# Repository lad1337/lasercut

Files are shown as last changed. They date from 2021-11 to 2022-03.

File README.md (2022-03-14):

# Lasercut

PCB and case for an "iso" 72 key mechanical keyboard

## Layout

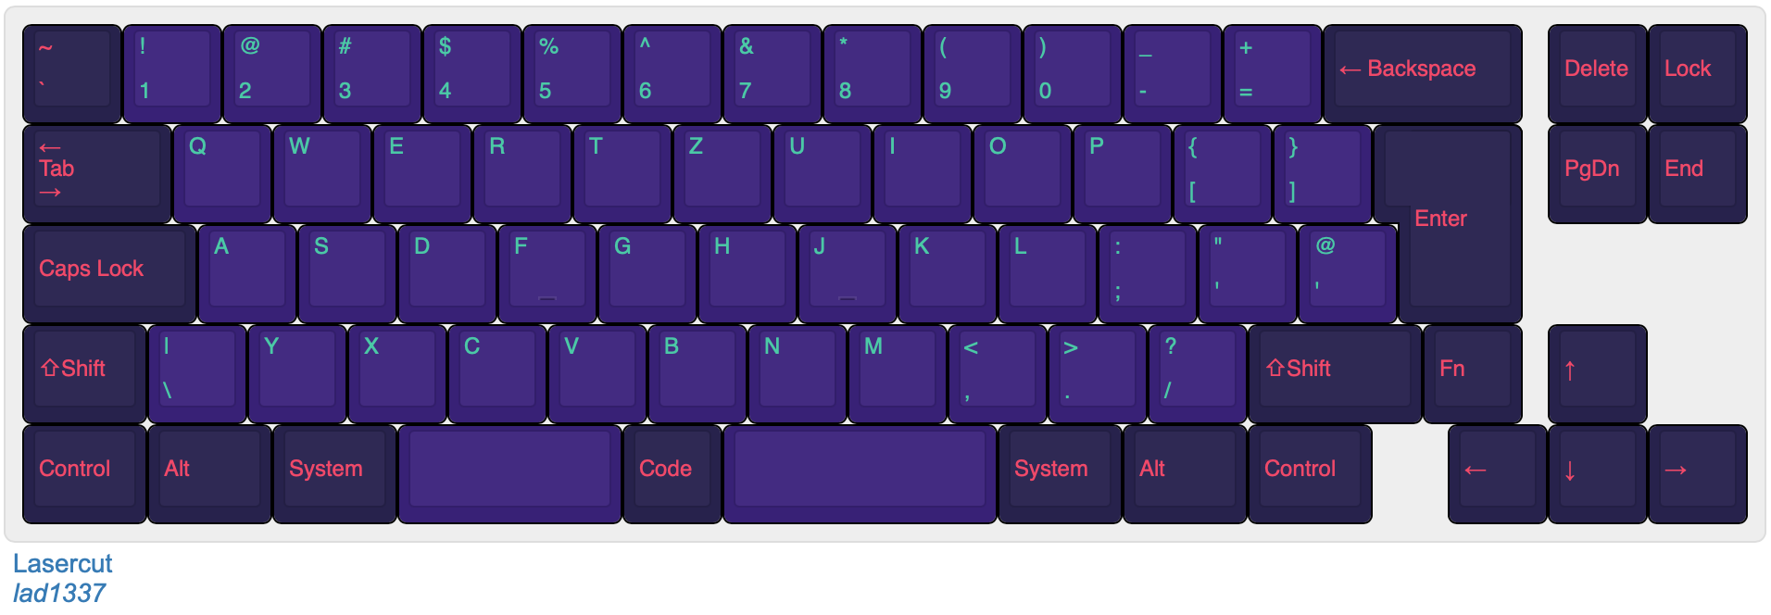
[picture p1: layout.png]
rendered image from keybaord layout editor


http://www.keyboard-layout-editor.com/#/gists/ba62eb48125304c6f380ac636846d038

## Case

The case is a sandwich style.
The plates can be rendered at http://builder.swillkb.com/
which is based on https://github.com/swill/kad.

in the case folder you will find a small go app(source) that can achive the same.

prerequisite:
    
    brew install inkscape pstoedit

render:

    cd case
    go run main.go

This will render svg, eps and dxf files.
These can be used with any CAD software.

You will need the following plates:

- 1x switch plate in 1.5mm
- 1x closed with magnets inserts in 3mm (not automatically rendered!!)
- 2x closed in 3mm
- 1x switch in 1.5mm
- 1x open in 3mm
- 1x bottom in 1-3mm

Example render in fusion with stainless steel and brass

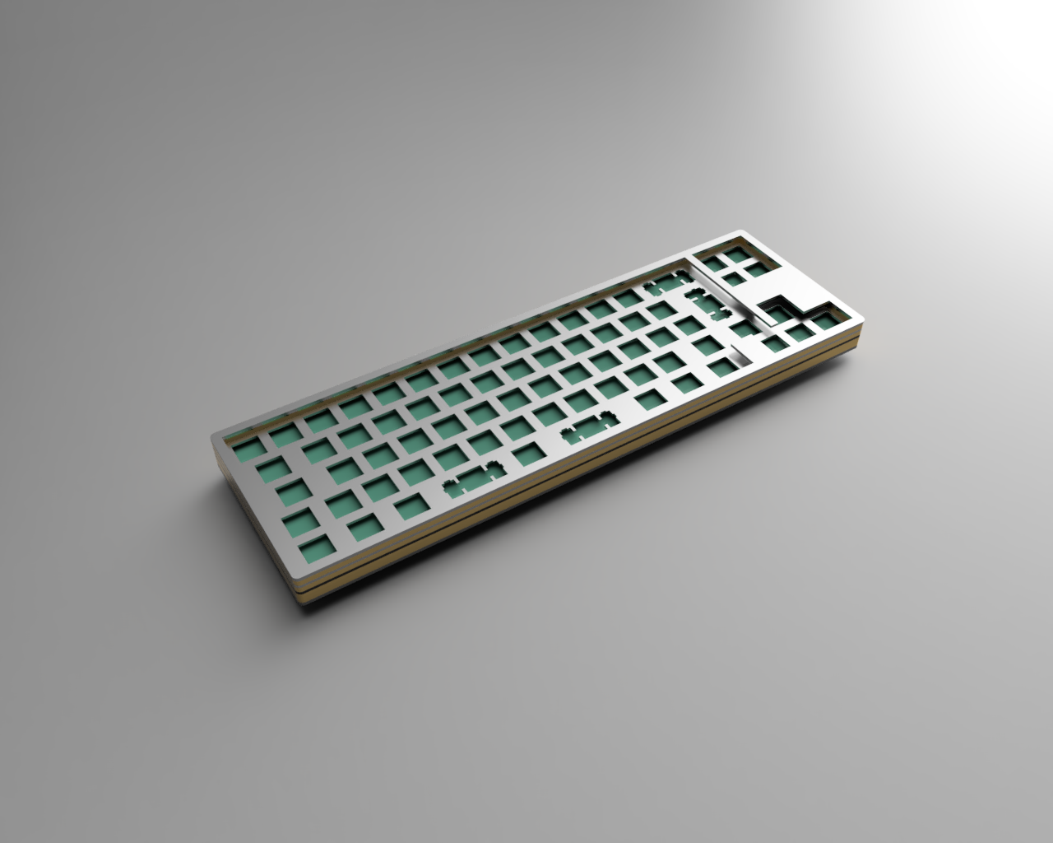
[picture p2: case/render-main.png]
3D render top side view

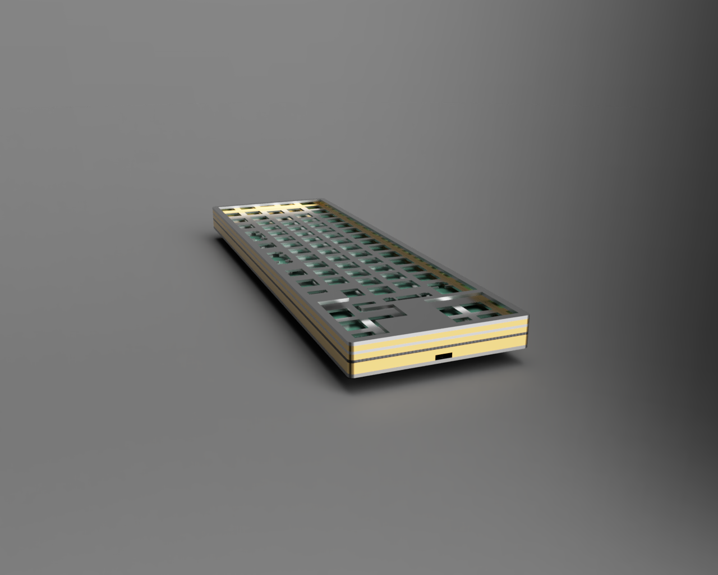
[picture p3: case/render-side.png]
3D render side view


## PCB

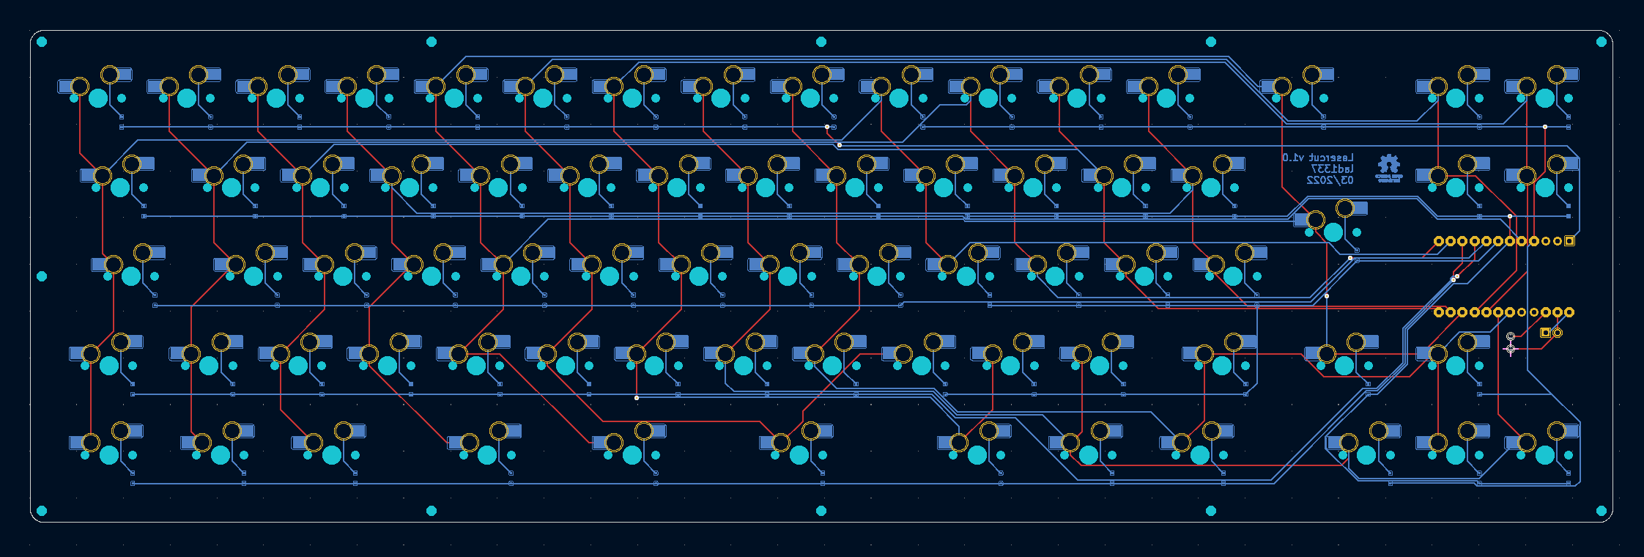
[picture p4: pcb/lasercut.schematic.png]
full board schematics

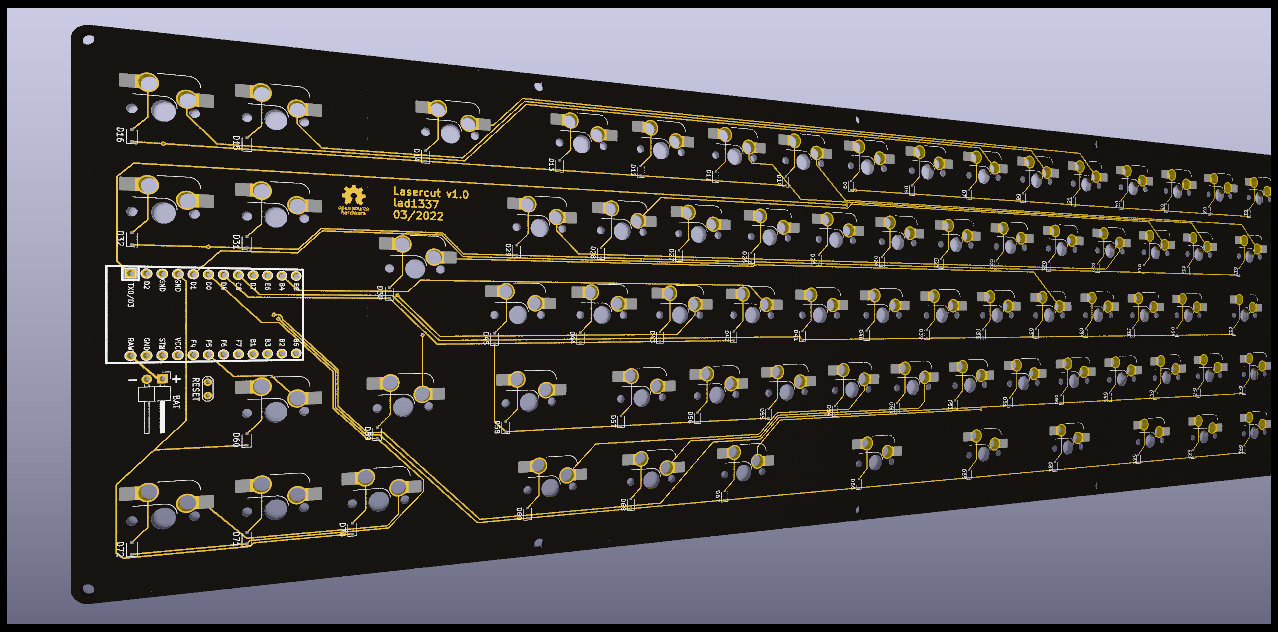
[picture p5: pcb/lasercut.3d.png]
3D render of PCB backside


### Board edge

add the generated `./case/Lasercut_bottom.dxf` to the board and position:

    x: 23.0
    y: 19.94769

TODO: mounting holes

### Netlist

prerequisite: 

- `kle2netlist` installed, see https://github.com/lad1337/kle2netlist
    this will create a netlist from the kle json
- `kicad-kbplacer` kicad plugin installed, see https://github.com/lad1337/kicad-kbplacer
    this is a plugin that will place the swiches to the right place as well as create some tracks
- `node` and `npm install @ijprest/kle-serial --save` 
    this is needed for converting the kle json to its internal format

Steps:

- run:
    `make netlist`
- import the netlist into pcbnew
- run the kicad-kbplacer plugin
- rearrage the controller

    ```
    x: 335.4
    y: 72.6
    roation: 180
    ```
- finish all the other tracks

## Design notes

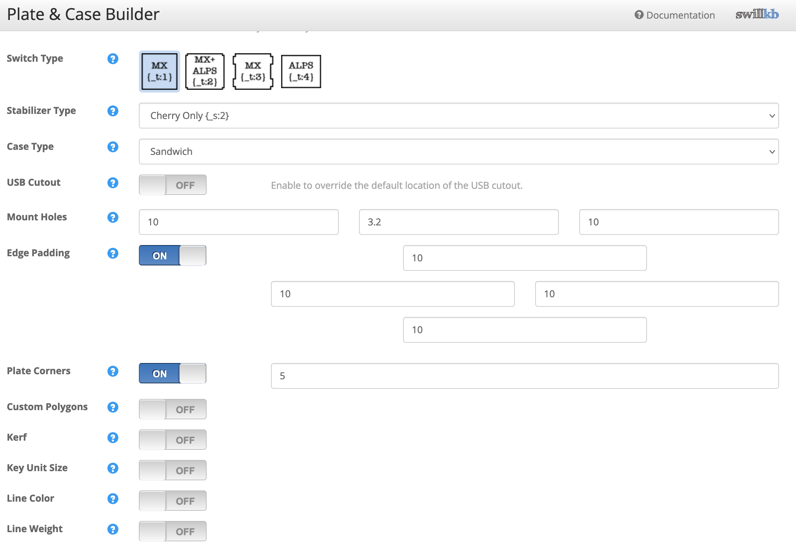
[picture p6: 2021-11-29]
case/Screenshot 2021-11-29 at 23.59.48.png

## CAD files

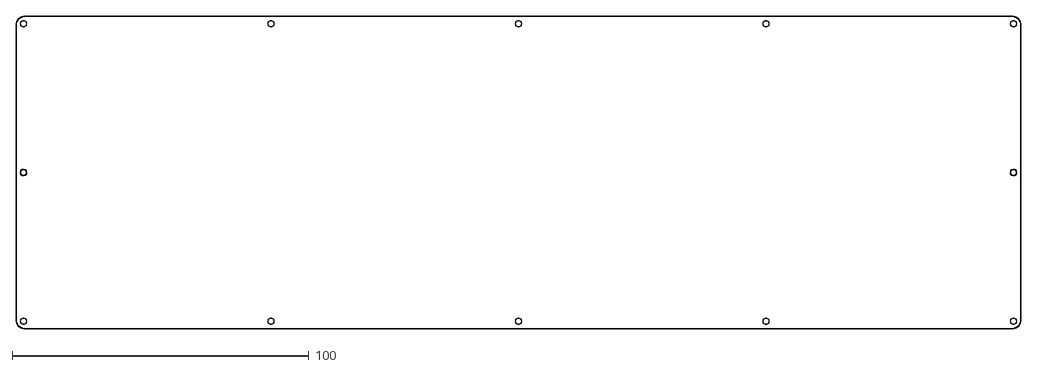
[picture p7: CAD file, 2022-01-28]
case/Lasercut_bottom.dxf
338.6 x 105.3

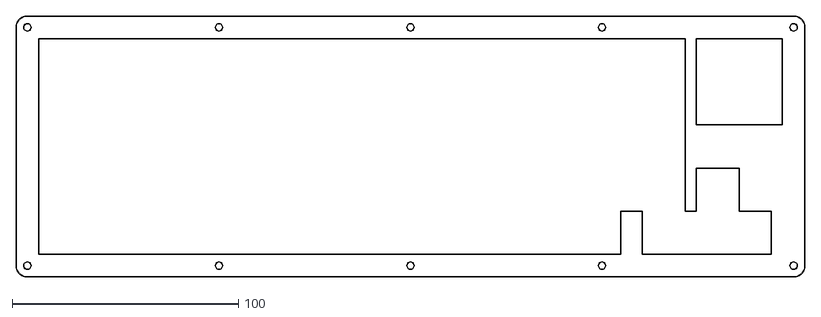
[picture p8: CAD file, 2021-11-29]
case/split space bar/f95ab37843878d62064d4762450dbb31d35d22d4_top.dxf
348.6 x 115.3

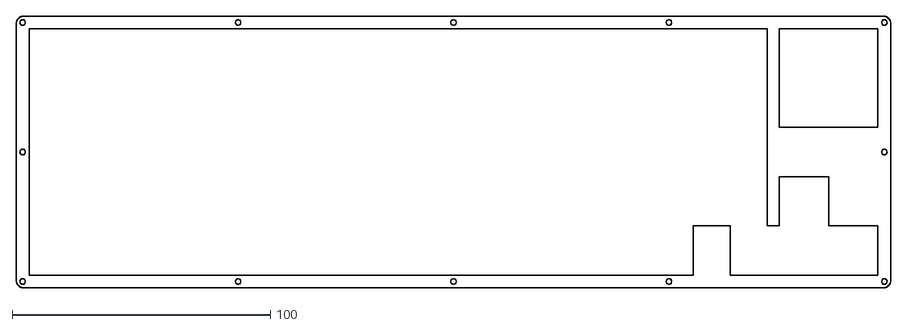
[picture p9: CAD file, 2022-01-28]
case/Lasercut_top.dxf
338.6 x 105.3

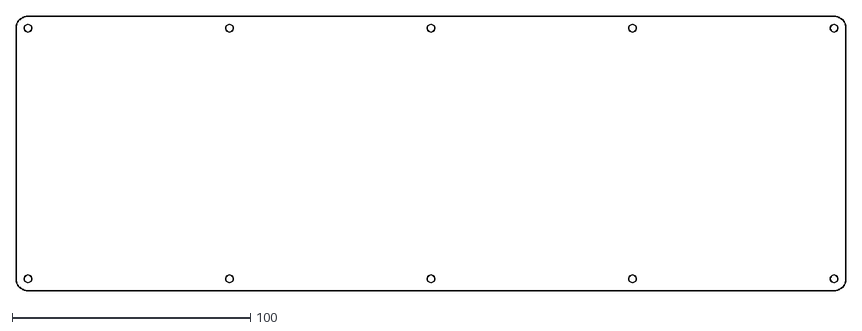
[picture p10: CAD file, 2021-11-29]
case/split space bar/f95ab37843878d62064d4762450dbb31d35d22d4_bottom.dxf
348.6 x 115.3

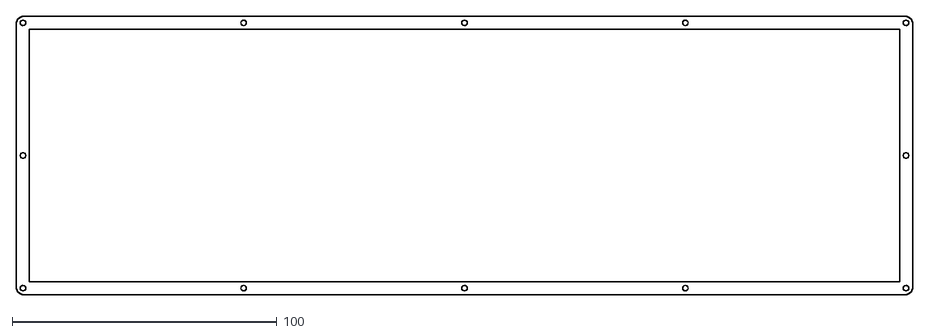
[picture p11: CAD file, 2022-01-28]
case/Lasercut_closed.dxf
338.6 x 105.3

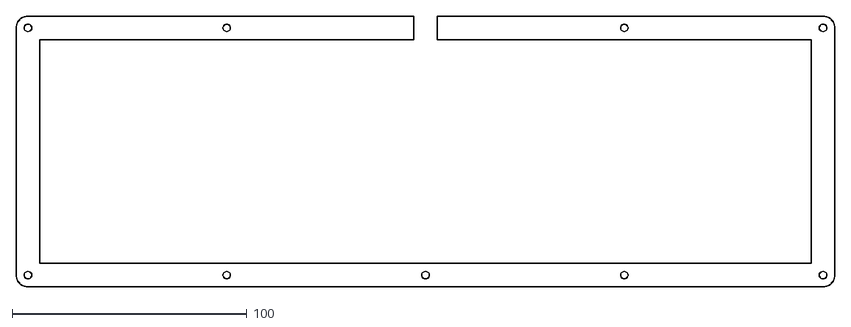
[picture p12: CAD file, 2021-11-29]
case/split space bar/f95ab37843878d62064d4762450dbb31d35d22d4_open.dxf
348.6 x 115.3

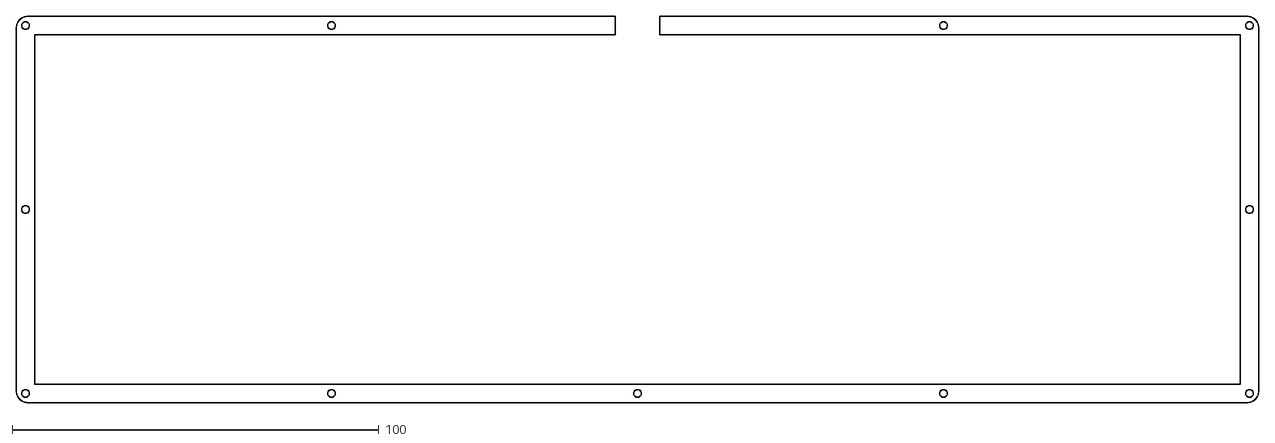
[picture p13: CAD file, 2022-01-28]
case/Lasercut_open.dxf
338.6 x 105.3

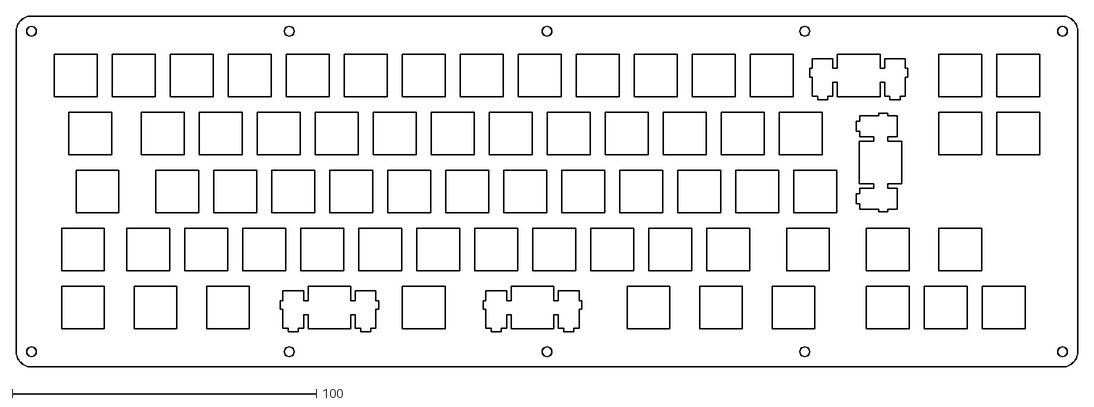
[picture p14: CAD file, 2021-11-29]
case/split space bar/f95ab37843878d62064d4762450dbb31d35d22d4_switch.dxf
348.6 x 115.3

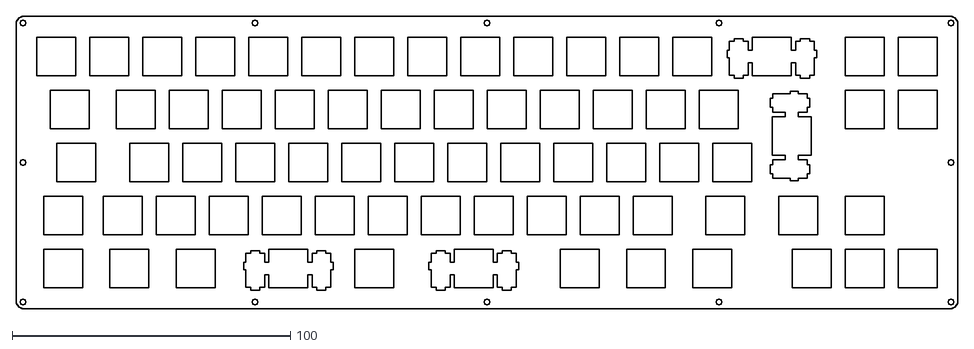
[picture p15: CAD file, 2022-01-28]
case/Lasercut_switch.dxf
338.6 x 105.3

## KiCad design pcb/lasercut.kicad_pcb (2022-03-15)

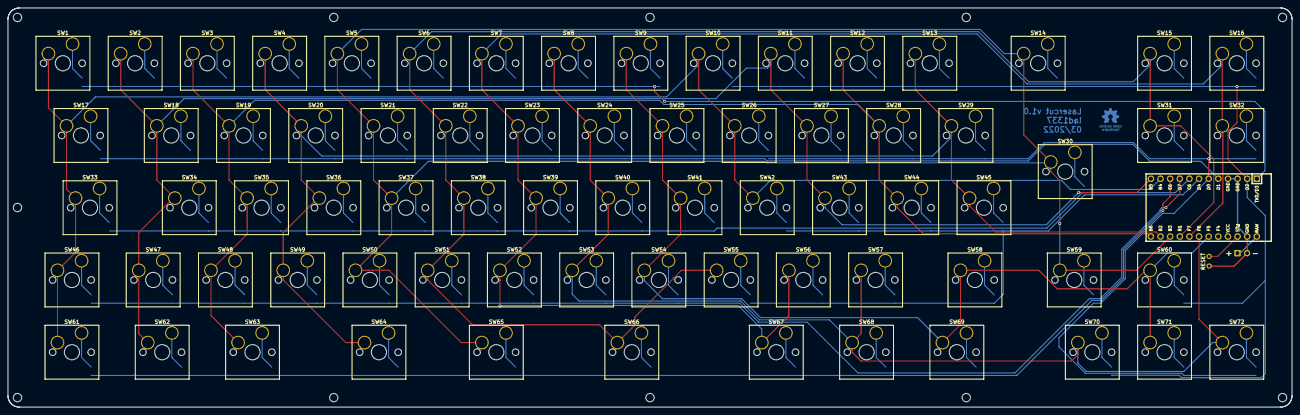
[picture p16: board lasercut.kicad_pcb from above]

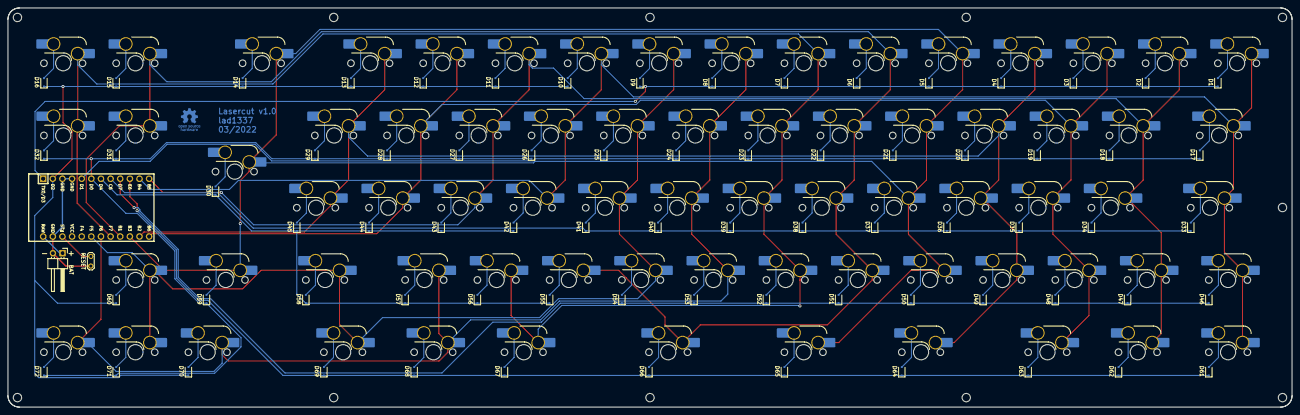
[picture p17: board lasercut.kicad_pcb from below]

Board: 2 copper layers, 338.6 x 105.3 mm, 147 parts (74 on the bottom side), 92 nets.

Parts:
BAT: PinHeader_1x02_P2.54mm_Horizontal
D1, D2, D3, D4, D5, D6, D7, D8, D9, D10, D11, D12, D13, D14, D15, D16, D17, D18, D19, D20, D21, D22, D23, D24, D25, D26, D27, D28, D29, D31, D32, D33, D34, D35, D36, D37, D38, D39, D40, D41, D42, D43, D44, D45, D46, D47, D48, D49, D50, D51, D52, D53, D54, D55, D56, D57, D58, D59, D60, D61, D62, D63, D64, D65, D66, D67, D68, D69, D70, D71, D72: 1N4148WS; D_SOD-323F
D30: D; D_SOD-323F
RESET: TestPoint_2Pads_Pitch2.54mm_Drill0.8mm
SW1, SW2, SW3, SW4, SW5, SW6, SW7, SW8, SW9, SW10, SW11, SW12, SW13, SW15, SW16, SW18, SW19, SW20, SW21, SW22, SW23, SW24, SW25, SW26, SW27, SW28, SW29, SW31, SW32, SW34, SW35, SW36, SW37, SW38, SW39, SW40, SW41, SW42, SW43, SW44, SW45, SW47, SW48, SW49, SW50, SW51, SW52, SW53, SW54, SW55, SW56, SW57, SW59, SW60, SW65, SW70, SW71, SW72: SW_Push; SW_Hotswap_Kailh_MX_plated_1.00u
SW14: SW_Push; SW_Hotswap_Kailh_MX_plated_2.00u
SW17: SW_Push; SW_Hotswap_Kailh_MX_plated_1.50u
SW30: SW_Push; SW_Hotswap_Kailh_MX_plated_ISOEnter
SW33, SW58: SW_Push; SW_Hotswap_Kailh_MX_plated_1.75u
SW46, SW61, SW62, SW63, SW67, SW68, SW69: SW_Push; SW_Hotswap_Kailh_MX_plated_1.25u
SW64: SW_Push; SW_Hotswap_Kailh_MX_plated_2.25u
SW66: SW_Push; SW_Hotswap_Kailh_MX_plated_2.75u
U: ProMicro; ArduinoProMicro

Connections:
BAT: BAT.1, U.24
COL0: SW1.1, SW10.1, SW17.1, SW26.1, SW33.1, SW42.1, SW46.1, SW61.1, U.11
COL1: SW2.1, SW11.1, SW18.1, SW27.1, SW34.1, SW43.1, SW47.1, SW62.1, U.12
COL2: SW3.1, SW12.1, SW19.1, SW28.1, SW35.1, SW44.1, SW48.1, SW63.1, U.13
COL3: SW4.1, SW13.1, SW20.1, SW29.1, SW36.1, SW45.1, SW49.1, SW64.1, U.14
COL4: SW5.1, SW14.1, SW21.1, SW30.1, SW37.1, SW50.1, SW59.1, SW65.1, U.15
COL5: SW6.1, SW15.1, SW22.1, SW31.1, SW38.1, SW51.1, SW55.1, SW66.1, U.16
COL6: SW7.1, SW16.1, SW23.1, SW32.1, SW39.1, SW52.1, SW56.1, SW67.1, U.17
COL7: SW8.1, SW24.1, SW40.1, SW53.1, SW57.1, SW68.1, SW70.1, SW72.1, U.18
COL8: SW9.1, SW25.1, SW41.1, SW54.1, SW58.1, SW60.1, SW69.1, SW71.1, U.19
GND: BAT.2, RESET.1, U.3, U.4, U.23
unnamed: D1.2, SW1.2
unnamed: D2.2, SW2.2
unnamed: D3.2, SW3.2
unnamed: D4.2, SW4.2
unnamed: D5.2, SW5.2
unnamed: D6.2, SW6.2
unnamed: D7.2, SW7.2
unnamed: D8.2, SW8.2
unnamed: D9.2, SW9.2
unnamed: D10.2, SW10.2
unnamed: D11.2, SW11.2
unnamed: D12.2, SW12.2
unnamed: D13.2, SW13.2
unnamed: D14.2, SW14.2
unnamed: D15.2, SW15.2
unnamed: D16.2, SW16.2
unnamed: D17.2, SW17.2
unnamed: D18.2, SW18.2
unnamed: D19.2, SW19.2
unnamed: D20.2, SW20.2
unnamed: D21.2, SW21.2
unnamed: D22.2, SW22.2
unnamed: D23.2, SW23.2
unnamed: D24.2, SW24.2
unnamed: D25.2, SW25.2
unnamed: D26.2, SW26.2
unnamed: D27.2, SW27.2
unnamed: D28.2, SW28.2
unnamed: D29.2, SW29.2
unnamed: D30.2, SW30.2
unnamed: D31.2, SW31.2
unnamed: D32.2, SW32.2
unnamed: D33.2, SW33.2
unnamed: D34.2, SW34.2
unnamed: D35.2, SW35.2
unnamed: D36.2, SW36.2
unnamed: D37.2, SW37.2
unnamed: D38.2, SW38.2
unnamed: D39.2, SW39.2
unnamed: D40.2, SW40.2
unnamed: D41.2, SW41.2
unnamed: D42.2, SW42.2
unnamed: D43.2, SW43.2
unnamed: D44.2, SW44.2
unnamed: D45.2, SW45.2
unnamed: D46.2, SW46.2
unnamed: D47.2, SW47.2
unnamed: D48.2, SW48.2
unnamed: D49.2, SW49.2
unnamed: D50.2, SW50.2
unnamed: D51.2, SW51.2
unnamed: D52.2, SW52.2
unnamed: D53.2, SW53.2
unnamed: D54.2, SW54.2
unnamed: D55.2, SW55.2
unnamed: D56.2, SW56.2
unnamed: D57.2, SW57.2
unnamed: D58.2, SW58.2
unnamed: D59.2, SW59.2
unnamed: D60.2, SW60.2
unnamed: D61.2, SW61.2
unnamed: D62.2, SW62.2
unnamed: D63.2, SW63.2
unnamed: D64.2, SW64.2
unnamed: D65.2, SW65.2
unnamed: D66.2, SW66.2
unnamed: D67.2, SW67.2
unnamed: D68.2, SW68.2
unnamed: D69.2, SW69.2
unnamed: D70.2, SW70.2
unnamed: D71.2, SW71.2
unnamed: D72.2, SW72.2
ROW0: D1.1, D2.1, D3.1, D4.1, D5.1, D6.1, D7.1, D8.1, D9.1, U.1
ROW1: D17.1, D18.1, D19.1, D20.1, D21.1, D22.1, D23.1, D24.1, D25.1, U.5
ROW2: D33.1, D34.1, D35.1, D36.1, D37.1, D38.1, D39.1, D40.1, D41.1, U.8
ROW3: D46.1, D47.1, D48.1, D49.1, D50.1, D51.1, D52.1, D53.1, D54.1, U.9
ROW4: D61.1, D62.1, D63.1, D64.1, D65.1, D66.1, D67.1, D68.1, D69.1, U.10
ROW5: D10.1, D11.1, D12.1, D13.1, D14.1, D15.1, D16.1, D60.1, D70.1, U.2
ROW6: D26.1, D27.1, D28.1, D29.1, D31.1, D32.1, D59.1, D71.1, D72.1, U.6
ROW7: D30.1, D42.1, D43.1, D44.1, D45.1, D55.1, D56.1, D57.1, D58.1, U.7
RST: RESET.2, U.22

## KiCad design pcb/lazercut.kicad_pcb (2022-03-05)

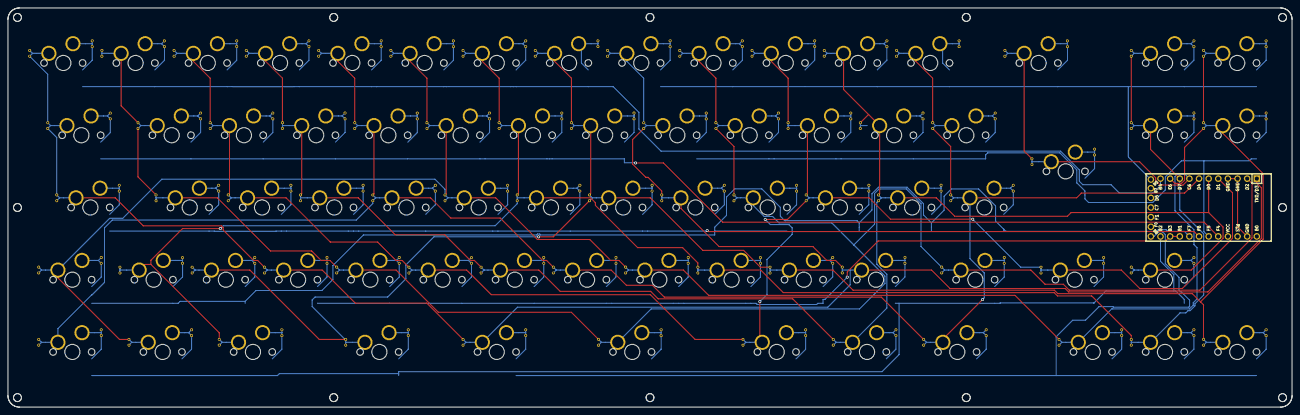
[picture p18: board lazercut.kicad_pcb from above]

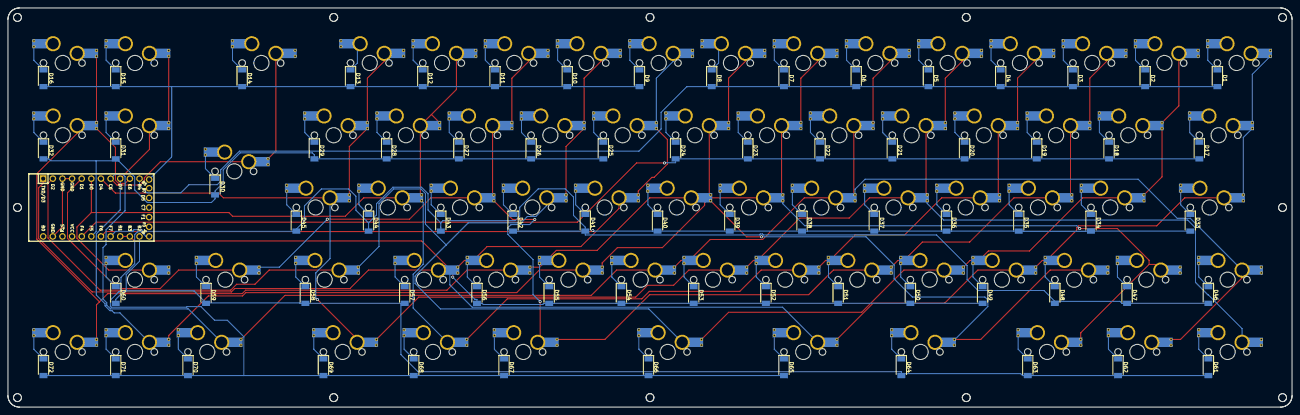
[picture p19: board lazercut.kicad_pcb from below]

Board: 2 copper layers, 338.6 x 105.3 mm, 145 parts (72 on the bottom side), 90 nets.

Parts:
D1, D2, D3, D4, D5, D6, D7, D8, D9, D10, D11, D12, D13, D14, D15, D16, D17, D18, D19, D20, D21, D22, D23, D24, D25, D26, D27, D28, D29, D30, D31, D32, D33, D34, D35, D36, D37, D38, D39, D40, D41, D42, D43, D44, D45, D46, D47, D48, D49, D50, D51, D52, D53, D54, D55, D56, D57, D58, D59, D60, D61, D62, D63, D64, D65, D66, D67, D68, D69, D70, D71, D72: D; D_SOD-128
SW1, SW2, SW3, SW4, SW5, SW6, SW7, SW8, SW9, SW10, SW11, SW12, SW13, SW14, SW15, SW16, SW17, SW18, SW19, SW20, SW21, SW22, SW23, SW24, SW25, SW26, SW27, SW28, SW29, SW30, SW31, SW32, SW33, SW34, SW35, SW36, SW37, SW38, SW39, SW40, SW41, SW42, SW43, SW44, SW45, SW46, SW47, SW48, SW49, SW50, SW51, SW52, SW53, SW54, SW55, SW56, SW57, SW58, SW59, SW60, SW61, SW62, SW63, SW64, SW65, SW66, SW67, SW68, SW69, SW70, SW71, SW72: SW_Push; MXOnly-1U-Hotswap-Antishear
U1: Elite-C

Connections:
GND: U1.3 (GND), U1.4 (GND), U1.23 (GND)
unnamed: D1.1 (K), SW1.2
unnamed: D2.1 (K), SW2.2
unnamed: D3.1 (K), SW3.2
unnamed: D4.1 (K), SW4.2
unnamed: D5.1 (K), SW5.2
unnamed: D6.1 (K), SW6.2
unnamed: D7.1 (K), SW7.2
unnamed: D8.1 (K), SW8.2
unnamed: D9.1 (K), SW9.2
unnamed: D10.1 (K), SW10.2
unnamed: D11.1 (K), SW11.2
unnamed: D12.1 (K), SW12.2
unnamed: D13.1 (K), SW13.2
unnamed: D14.1 (K), SW14.2
unnamed: D15.1 (K), SW15.2
unnamed: D16.1 (K), SW16.2
unnamed: D17.1 (K), SW17.2
unnamed: D18.1 (K), SW18.2
unnamed: D19.1 (K), SW19.2
unnamed: D20.1 (K), SW20.2
unnamed: D21.1 (K), SW21.2
unnamed: D22.1 (K), SW22.2
unnamed: D23.1 (K), SW23.2
unnamed: D24.1 (K), SW24.2
unnamed: D25.1 (K), SW25.2
unnamed: D26.1 (K), SW26.2
unnamed: D27.1 (K), SW27.2
unnamed: D28.1 (K), SW28.2
unnamed: D29.1 (K), SW29.2
unnamed: D30.1 (K), SW30.2
unnamed: D31.1 (K), SW31.2
unnamed: D32.1 (K), SW32.2
unnamed: D33.1 (K), SW33.2
unnamed: D34.1 (K), SW34.2
unnamed: D35.1 (K), SW35.2
unnamed: D36.1 (K), SW36.2
unnamed: D37.1 (K), SW37.2
unnamed: D38.1 (K), SW38.2
unnamed: D39.1 (K), SW39.2
unnamed: D40.1 (K), SW40.2
unnamed: D41.1 (K), SW41.2
unnamed: D42.1 (K), SW42.2
unnamed: D43.1 (K), SW43.2
unnamed: D44.1 (K), SW44.2
unnamed: D45.1 (K), SW45.2
unnamed: D46.1 (K), SW46.2
unnamed: D47.1 (K), SW47.2
unnamed: D48.1 (K), SW48.2
unnamed: D49.1 (K), SW49.2
unnamed: D50.1 (K), SW50.2
unnamed: D51.1 (K), SW51.2
unnamed: D52.1 (K), SW52.2
unnamed: D53.1 (K), SW53.2
unnamed: D54.1 (K), SW54.2
unnamed: D55.1 (K), SW55.2
unnamed: D56.1 (K), SW56.2
unnamed: D57.1 (K), SW57.2
unnamed: D58.1 (K), SW58.2
unnamed: D59.1 (K), SW59.2
unnamed: D60.1 (K), SW60.2
unnamed: D61.1 (K), SW61.2
unnamed: D62.1 (K), SW62.2
unnamed: D63.1 (K), SW63.2
unnamed: D64.1 (K), SW64.2
unnamed: D65.1 (K), SW65.2
unnamed: D66.1 (K), SW66.2
unnamed: D67.1 (K), SW67.2
unnamed: D68.1 (K), SW68.2
unnamed: D69.1 (K), SW69.2
unnamed: D70.1 (K), SW70.2
unnamed: D71.1 (K), SW71.2
unnamed: D72.1 (K), SW72.2
col0: D1.2 (A), D2.2 (A), D3.2 (A), D4.2 (A), D5.2 (A), D6.2 (A), D7.2 (A), D8.2 (A), U1.11 (8/PB4)
col1: D9.2 (A), D10.2 (A), D11.2 (A), D12.2 (A), D13.2 (A), D14.2 (A), D15.2 (A), D16.2 (A), U1.12 (9/PB5)
col2: D17.2 (A), D18.2 (A), D19.2 (A), D20.2 (A), D21.2 (A), D22.2 (A), D23.2 (A), D24.2 (A), U1.20 (A3/PF4)
col3: D25.2 (A), D26.2 (A), D27.2 (A), D28.2 (A), D29.2 (A), D30.2 (A), D31.2 (A), D32.2 (A), U1.19 (A2/PF5)
col4: D33.2 (A), D34.2 (A), D35.2 (A), D36.2 (A), D37.2 (A), D38.2 (A), D39.2 (A), D40.2 (A), U1.18 (A1/PF6)
col5: D41.2 (A), D42.2 (A), D43.2 (A), D44.2 (A), D45.2 (A), D46.2 (A), D47.2 (A), D48.2 (A), U1.17 (A0/PF7)
col6: D49.2 (A), D50.2 (A), D51.2 (A), D52.2 (A), D53.2 (A), D54.2 (A), D55.2 (A), D56.2 (A), U1.15 (14/PB3), U1.16 (15/PB1)
col7: D57.2 (A), D58.2 (A), D59.2 (A), D60.2 (A), D61.2 (A), D62.2 (A), D63.2 (A), D64.2 (A), U1.14 (16/PB2)
col8: D65.2 (A), D66.2 (A), D67.2 (A), D68.2 (A), D69.2 (A), D70.2 (A), D71.2 (A), D72.2 (A), U1.13 (10/PB6)
row0: SW1.1, SW9.1, SW17.1, SW25.1, SW33.1, SW41.1, SW49.1, SW57.1, SW65.1, U1.1 (TX0/PD3)
row1: SW2.1, SW10.1, SW18.1, SW26.1, SW34.1, SW42.1, SW50.1, SW58.1, SW66.1, U1.2 (RX1/PD2)
row2: SW3.1, SW11.1, SW19.1, SW27.1, SW35.1, SW43.1, SW51.1, SW59.1, SW67.1, U1.5 (2/PD1)
row3: SW4.1, SW12.1, SW20.1, SW28.1, SW36.1, SW44.1, SW52.1, SW60.1, SW68.1, U1.6 (3/PD0)
row4: SW5.1, SW13.1, SW21.1, SW29.1, SW37.1, SW45.1, SW53.1, SW61.1, SW69.1, U1.7 (4/PD4)
row5: SW6.1, SW14.1, SW22.1, SW30.1, SW38.1, SW46.1, SW54.1, SW62.1, SW70.1, U1.8 (5/PC6)
row6: SW7.1, SW15.1, SW23.1, SW31.1, SW39.1, SW47.1, SW55.1, SW63.1, SW71.1, U1.9 (6/PD7)
row7: SW8.1, SW16.1, SW24.1, SW32.1, SW40.1, SW48.1, SW56.1, SW64.1, SW72.1, U1.10 (7/PE6)

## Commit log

2021-10-08 initial setup
    [lazercut.kicad_pcb, lazercut.sch]
2021-10-08 finished tutorial
    [bottom.dxf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]
2021-10-26 nuke ... restating the project
    [bottom.dxf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]
2021-11-29 a new hope
    [f95ab37843878d62064d4762450dbb31d35d22d4_bottom.dxf, f95ab37843878d62064d4762450dbb31d35d22d4_open.dxf, f95ab37843878d62064d4762450dbb31d35d22d4_switch.dxf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]
2022-01-28 add case render app and add rendered image
    [Lasercut_bottom.dxf, Lasercut_closed.dxf, Lasercut_open.dxf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]
2022-03-05 re do pcb aligment and traceing
    [lasercut.dsn, lazercut.kicad_pcb, lazercut.kicad_sch]
2022-03-05 reposition elite-c because of outer frame
    [lasercut.dsn, lazercut.kicad_pcb]
2022-03-06 add gerber and more images
    [lasercut.kicad_pcb, lasercut.kicad_sch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]
2022-03-06 add batter headers
    [lasercut.dsn, lasercut.kicad_pcb, lasercut.kicad_sch]
2022-03-07 new freerouting version
    need to redo the matrix/switch position
    [lasercut.dsn, lasercut.kicad_pcb, lasercut.kicad_sch]
2022-03-14 cleanup and makefile with some tools
    [lasercut.dsn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]
2022-03-14 new pcb kicad project
    [lasercut.kicad_pcb, lasercut.kicad_sch]
2022-03-14 add kicad parts library modules
2022-03-14 add kicad cache files ... not sure if this is cool
2022-03-14 add battery connector and images
    [lasercut.kicad_pcb]
2022-03-14 add gerber files
    [lasercut-B_Cu.gbl, lasercut-B_Cu.gbr, lasercut-B_Mask.gbr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]
2022-03-14 update readme with pcb instructions
2022-03-15 FIX: Row5 was connected to GND
    [lasercut.kicad_pcb]
